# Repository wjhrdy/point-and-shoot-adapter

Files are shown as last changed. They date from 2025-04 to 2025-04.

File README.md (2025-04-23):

# L39 Adapter OpenSCAD Project

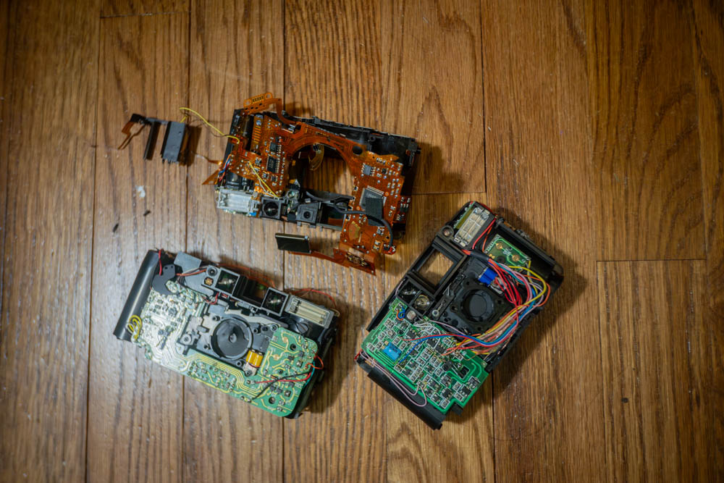
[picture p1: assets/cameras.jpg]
broken point and shoot cameras


## Overview
This project generates a parametric Leica L39 (LTM) to lens adapter with a knurled grip, using OpenSCAD and open-source libraries for threads and knurling.

> [!WARNING]
> If you are not careful, it is possible to design and print an adapter that, when screwed into your camera, could protrude so far that it physically touches or damages your camera's sensor or shutter. Always measure carefully and double-check your design before mounting on your camera. The authors and contributors are not responsible for any damage caused by improper use of these adapters.

## Structure
- `l39-adapter.scad` — Main OpenSCAD source file (auto-generated from template)
- `l39-adapter.template.scad` — Template for the adapter, with a placeholder for lens profile includes
- `lenses/` — Directory containing individual lens profile SCAD files
- `libs/` — Contains OpenSCAD library dependencies (downloaded automatically)
- `output/` — STL and other generated output
- `justfile` — Automation for dependency management and builds

## Quick Start
1. Install [OpenSCAD](https://openscad.org/) and [`just`](https://just.systems/)
2. Clone this repo
3. Fetch dependencies:
   ```sh
   just deps
   ```
4. Build a default adapter:
   ```sh
   just build __brand-model-focallength-fstop
   ```
   Or build for a specific lens profile:
   ```sh
   just build nikon-fun_touch_6-28mm-f5.6
   ```
   This will generate an STL in the `output/` directory using the selected lens profile.

## Print Settings

These adapters were tested on a Bambu Lab P1P with a 0.4mm nozzle using PLA, but most filaments should work. Because the adapter has fine threads, print quality and settings matter for a good fit. Recommended settings:

- **Layer Height:** 0.16mm (optimal for threads)
- **Top/Bottom Layers:** 3 each
- **Infill:** 20% grid
- **Seam Position:** Random (for thread integrity)
- **Joints:** Scarf joints for contours and holes
- **Other Settings:** Defaults in Orca Slicer unless otherwise noted

These settings provide strong, clean threads and a good fit for most lenses. If you use a different printer or filament, you may need to fine-tune for best results.

## Customization
- To create a new lens adapter, copy `lenses/__brand-model-focallength-fstop.scad` to a new file in the `lenses/` directory and edit the parameters for your lens:
  - `lens_hole_diam` — Inner diameter for your lens
  - `lens_cyl_depth` — Depth of the lens holding cylinder
  - `knurl_height` — Height of the knurled ring
  - `lens_offset` — Controls how recessed or protruding the lens sits
  - `l39_thread_length` — Thread length for the adapter
- Build with your new profile using:
  ```sh
  just build your-profile-filename
  ```
- The build system will automatically substitute the correct include for your chosen lens profile.

## Lens Profile Guide

Each lens profile SCAD file should define the following parameters:

```scad
lens_hole_diam = ...;    // mm, lens hole inner diameter (configurable)
lens_cyl_depth = ...;    // mm, depth of lens holding cylinder
knurl_height = ...;      // mm, height of knurled ring
lens_offset = ...;       // mm, positive = lens protrudes, zero/negative = flush or recessed
l39_thread_length = ...; // mm, total thread length
```

## Achieving Focus

To use these adapted lenses with precise focusing on a mirrorless camera, you can combine this custom L39 adapter with two additional components:

1. **L39-to-M Mount Adapter:**
   - This thin adapter converts the Leica L39 (LTM) thread to Leica M mount. These are widely available and inexpensive.
2. **M Mount Helicoid Adapter:**
   - This is a variable extension tube ("helicoid") with Leica M mount on both sides. It allows you to finely adjust the lens-to-sensor distance, enabling close focus or correcting for flange differences.

**Typical workflow:**
- Attach your lens to the 3D-printed L39 adapter.
- Screw the L39 adapter into the L39-to-M adapter.
- Mount the combined unit onto the M-mount helicoid adapter.
- Attach the assembly to your mirrorless camera using an M-mount-to-camera adapter (if needed).
- Use the helicoid to achieve focus, including infinity and macro distances.

This setup is especially useful for adapting compact point-and-shoot or rangefinder lenses to digital mirrorless systems, giving you full manual focus control.

> [!TIP] 
> If you want a cheap way to get close focus, you can simply use the threads of the L39 mount to move your lens forward. Unscrewing the adapter slightly brings the lens closer to the subject, allowing for macro or closer focusing without any extra adapters.

### Measurement & Setup Tips

measure from the front housing of the lens back to the first lip or largest lip.
cross section of lens diagram

```
        lens_cyl_depth
             ____
            ⬇  ⬇
        |  |
        |  |
   _____|  |_____    __
  /              \     |
 /                \    |
|                  |   | lens_hole_diam
|                  |   |
 \                /    |
  \____ ____ ____/   __|
        |  | 
        |  | 
back    |  |  front 
```
- Measure the largest diameter and the depth of the lens section to determine `lens_hole_diam` and `lens_cyl_depth`.
- Print with default parameters to test fit and measure the offset and knurl height.
- Seat the lens in the adapter and screw into the camera. Adjust `lens_offset` so the lens focuses to infinity:
  - `lens_offset = 0` for a flat lens
  - `lens_offset = -5` to `-10` for a recessed lens
- A positive `lens_offset` is possible but will make the lens more exposed and harder to print.

```
                              ____
                             ⬇  ⬇ (negative)lens_offset 
                             (this should be zero or >= for ease of printing)
 ⬇ lens mount face
 |                               /
 |                   |  |       /
 |                   |  |      /
 |              _____|  |_____/
 |             /              \  
 |            /                \
 |           |                  |
 |           |                  |
 |            \                /
 |             \______________/
 |                   |  |     \
 |                   |  |      \
 |                   |  |       \
 |                               \      
                        
 ⬆_______________________________⬆ knurl_height
```

## TODO

- **Custom Rear Aperture:**
  Many of these point-and-shoot lenses can benefit from an additional aperture (stop) placed behind the lens to improve image quality or control flare. Measuring the exact position for optimal placement can be tricky, but modeling and 3D printing a simple aperture disk or insert to fit over the back of the lens is straightforward. Experimentation is encouraged—contributions and shared designs are welcome!

## Library Sources
- [threads.scad](https://github.com/rcolyer/threads-scad)
- [knurled-openscad](https://github.com/smkent/knurled-openscad)

## License
See individual libraries for their respective licenses.

## Contributing
Contributions are welcome! Please open an issue or submit a pull request.

---

> [!NOTE]
> Only use broken point and shoot cameras for your lens conversions. Please don't buy up a scarce resource and make these silly lenses from working cameras. Let's keep vintage cameras available for everyone!

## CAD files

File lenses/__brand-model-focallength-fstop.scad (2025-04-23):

// measure from the front housing of the lens back to the first lip or largest lip.
// cross section of lens diagram

//         lens_cyl_depth
//              ____
//             ⬇  ⬇
//         |  |
//         |  |
//    _____|  |_____    __
//   /              \     |
//  /                \    |
// |                  |   | lens_hole_diam
// |                  |   |
//  \                /    |
//   \____ ____ ____/   __|
//         |  | 
//         |  | 
// back    |  |  front 

// measure the largest diameter of this section
// measure the depth of this section

lens_hole_diam = 16.78;          // mm, lens hole inner diameter (configurable)
lens_cyl_depth = 4;           // mm, depth of lens holding cylinder

// print with the default params this will let you measure the offset and knurl height

knurl_height = 5;              // mm, height of knurled ring
lens_offset = -5;             // mm, positive = lens protrudes in front of knurled face, zero/negative = flush or recessed
l39_thread_length = 15;        // mm, total thread length reset to 5 after testing.

// measure the offset and knurl height
// seat the lens in the adapter and screw it in to the camera
// screw it in until you are focused on infinity then measure the height of the knurled ring
// decide if you want a flat lens or a recessed lens and set lens_offset accordingly.
// lens_offset = 0 for a flat lens, lens_offset = -5 to -10 for a recessed lens
// sometimes a flat lens might not work if the face of the lens needs to be 
// to close to the lens mount face

// you can make a positive lens offset but it will be harder 
// to print and your lens will be more exposed.

//                               ____
//                              ⬇  ⬇ (negative)lens_offset (this should be zero or >= 5 for ease of printing)
//  ⬇ lens mount face
//  |                               /
//  |                   |  |       /
//  |                   |  |      /
//  |              _____|  |_____/
//  |             /              \  
//  |            /                \
//  |           |                  |
//  |           |                  |
//  |           \                /
//  |            \____ ____ ____/
//  |                   |  |     \
//  |                   |  |      \
//  |                   |  |       \
//  |                               \      
//                       
//  ⬆_______________________________⬆ knurl_height
// 

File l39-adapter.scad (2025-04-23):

// l39-adapter.scad
// Parametric Leica L39 (LTM) to variable hole knurled tapered adapter
// Uses: rcolyer/threads-scad for threads, knurled-openscad for knurling
// User can set: hole_diameter, wall_thickness, adapter_length, knurl_height, knurl_pitch

// =====================
// Lens Parameters
// =====================
include <lenses/yashika-t4-35mm-f3.5.scad>;

// =====================
// User Parameters
// =====================
knurl_diam = 47.37;           // mm, diameter of knurled ring
knurl_width = 2;              // mm, width of each knurl (smaller = finer)
knurl_height_param = 2;     // mm, height of each knurl (smaller = finer)
knurl_depth = 1.5;             // mm, depth of each knurl
knurl_bevel = 1.3;              // mm, flat face (no bevel)
cone_outer_diam = 38.5;       // mm, diameter at front face of cone

// Thread best-practice parameters
l39_outer_diam = 39;          // mm, nominal L39 thread outer diameter
l39_pitch = 0.977;            // mm (26 tpi)
l39_tooth_angle = 30;
l39_thread_outer_diam_print = l39_outer_diam - 0.19; // actual printed outer diameter
lens_cut_diam = l39_outer_diam - 10; // mm, user-specified inner diameter for thread cutout (for lens seating)
lens_extrude_diam = lens_hole_diam + 5; // mm, user-specified inner diameter for thread cutout (for lens seating)

// =====================
// Derived Parameters
// =====================
thread_top_z = knurl_height + l39_thread_length;
lens_mount_z = lens_offset; // Mounting face (top of lens mounting hole)
lens_hole_top_z = lens_mount_z + lens_cyl_depth;

// =====================
// Libraries
// =====================
// Uncomment and set path to libraries as needed
use <libs/threads.scad>;
use <libs/knurled.scad>;

// =====================
// Main Adapter Module
// =====================

module l39_adapter() {
    difference() {
        union() {
            // 1. Knurled ring (front, large diameter)
            // Knurled ring (optimize knurl_width/height/segments for speed if possible)
            knurled_cylinder(
                diameter=knurl_diam,
                height=knurl_height,
                knurl_width=knurl_width, // Consider increasing for fewer knurls
                knurl_height=knurl_height_param,
                knurl_depth=knurl_depth,
                bevel=knurl_bevel
            );
            // 2. Threaded section (solid core and shell)
            // Threaded section (optimize thread quality for speed if possible)
            translate([0,0,knurl_height])
                ScrewThread(
                    outer_diam=l39_thread_outer_diam_print,
                    height=l39_thread_length,
                    pitch=l39_pitch,
                    tooth_angle=l39_tooth_angle
                );
            // 3. Support cylinder if mounting face is above thread section
            if (lens_offset + lens_cyl_depth > thread_top_z) {
                translate([0,0,thread_top_z])
                    // Lower $fn for faster rendering
                    cylinder(h=(lens_offset + lens_cyl_depth) - thread_top_z, d=lens_extrude_diam, $fn=48);
            }
        }

// Subtraction logic
if (lens_offset == 0) {
    // Hole from front face to lens_cyl_depth
    translate([0,0,0])
        cylinder(h=lens_cyl_depth, d=lens_hole_diam, $fn=120);
    // If lens_cyl_depth < thread_top_z, subtract cylinder up to thread_top_z
    if (lens_cyl_depth < thread_top_z) {
        translate([0,0,lens_cyl_depth])
            // Lower $fn for faster rendering
            cylinder(h=thread_top_z - lens_cyl_depth, d=lens_cut_diam, $fn=48);
    }
} else {
    // Front geometry logic (always from bottom/front face z=0)
    if (lens_offset > 0) {
        // Cone from z=0 (large) to z=-lens_offset (small)
        translate([0,0,-lens_offset])
            // Lower $fn for faster rendering
            cylinder(h=lens_offset, d1=cone_outer_diam, d2=lens_hole_diam, $fn=48);
        // Lens hole from z=-lens_offset up by lens_cyl_depth
        translate([0,0,-lens_offset])
            cylinder(h=lens_cyl_depth, d=lens_hole_diam, $fn=120);
    } else if (lens_offset < 0) {
        // Negative cone from front face to mounting face (z=0 to z=-lens_offset)
        translate([0,0,0])
            // Lower $fn for faster rendering
            cylinder(h=-lens_offset, d1=cone_outer_diam, d2=lens_hole_diam, $fn=48);
        // Lens hole from z=lens_offset up by lens_cyl_depth
        translate([0,0,-lens_offset])
            cylinder(h=lens_cyl_depth, d=lens_hole_diam, $fn=120);
    }
    // If top of lens hole < thread_top_z, subtract cylinder up to thread_top_z
    lens_hole_top = -lens_offset + lens_cyl_depth;
    if (lens_hole_top < thread_top_z) {
        translate([0,0,lens_hole_top])
            // Lower $fn for faster rendering
            cylinder(h=thread_top_z - lens_hole_top, d=lens_cut_diam, $fn=48);
    }
}
    }
}

// =====================
// Preview
// =====================
l39_adapter();

// =====================
// Notes
// =====================
// - For threads, download and use rcolyer/threads-scad: https://github.com/rcolyer/threads-scad
// - For knurling, download and use knurled-openscad: https://github.com/smkent/knurled-openscad
// - Uncomment use<> lines and knurl/thread code as needed
// - All key dimensions are parametric

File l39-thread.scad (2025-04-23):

// l39-thread.scad
// Minimal test: generates only the Leica L39 thread for print/fit testing
// Requires: rcolyer/threads-scad (https://github.com/rcolyer/threads-scad)

// Thread parameters (copied from l39-adapter.scad)
l39_outer_diam = 39;          // mm, nominal L39 thread outer diameter
l39_pitch = 0.977;            // mm (26 tpi)
l39_tooth_angle = 30;
l39_thread_outer_diam_print = l39_outer_diam - 0.2; // actual printed outer diameter
l39_thread_length = 4.32;     // mm, total thread length

// Library
use <libs/threads.scad>;

// Minimal thread test
ScrewThread(
    outer_diam=l39_thread_outer_diam_print,
    height=l39_thread_length,
    pitch=l39_pitch,
    tooth_angle=l39_tooth_angle
);

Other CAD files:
l39-adapter.template.scad
lenses/nikon-fun_touch_4-29mm-f4.5.scad
lenses/nikon-fun_touch_6-28mm-f5.6.scad
lenses/yashika-t4-35mm-f3.5.scad

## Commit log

2025-04-23 Add warning about potential camera damage from improper adapter design
2025-04-23 Update lens parameters to use Nikon Fun Touch 4 29mm f/4.5 lens
    [l39-adapter.scad]
2025-04-23 Add warning about using broken cameras and update image in README
2025-04-23 Add Yashica T4 35mm lens adapter with STL output and template updates
    [l39-adapter.template.scad, yashika-t4-35mm-f3.5.scad]
2025-04-23 Update lens parameters for Yashika T4 adapter: hole diameter, knurl height, offset
    [__brand-model-focallength-fstop.scad, l39-adapter.scad, yashika-t4-35mm-f3.5.scad]
